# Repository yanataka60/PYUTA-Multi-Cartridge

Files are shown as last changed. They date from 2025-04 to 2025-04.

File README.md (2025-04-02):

# TOMY ぴゅう太用Multi Cartridge

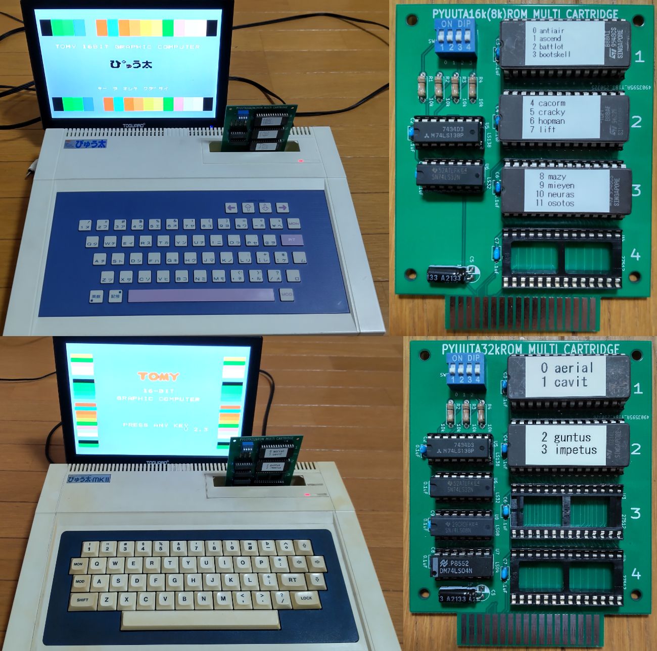
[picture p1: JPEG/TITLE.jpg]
Multi Cartridge


　いぬふとさんがたくさんのレトロPC用自作プログラムを公開してくださっており、ぴゅう太用としてはROMイメージでの公開となっています。

　そこで実機で気楽に遊べるようROMイメージをディップスイッチで切り替えられるカートリッジを作ってみました。

　公開されているROMイメージには(>8000～)、(>4000～)の二種類があり、それぞれ(>8000～)用の16K(8K)ROM Multi Cartridgeと(4000～)用の32KROM Multi Cartridgeを使用します。

#### 注)32KROM Multi Cartridgeを初代ぴゅう太で使用するにはゲームアダプター相当品が必要です。初代ぴゅう太のカートリッジスロットに32KROM Multi Cartridgeを挿入しても動作しません。

　16K(8K)ROM Multi Cartridgeはぴゅう太、ぴゅう太mk2で動作確認、32KROM Multi Cartridgeはぴゅう太+ゲームアダプター相当品、ぴゅう太mk2で動作確認を行いましたが、ぴゅう太Jr.も両方とも動作すると思います。

　なお、当然ですがROMへ書き込むための機器が別途必要となります。

## 16K(8K)ROM Multi Cartridge
### 回路図
　KiCadフォルダ内のPYUTA16k.pdfを参照してください。

[回路図](https://github.com/yanataka60/PYUTA-Multi-Cartridge/blob/main/Kicad/16K/PYUTA16k.pdf)

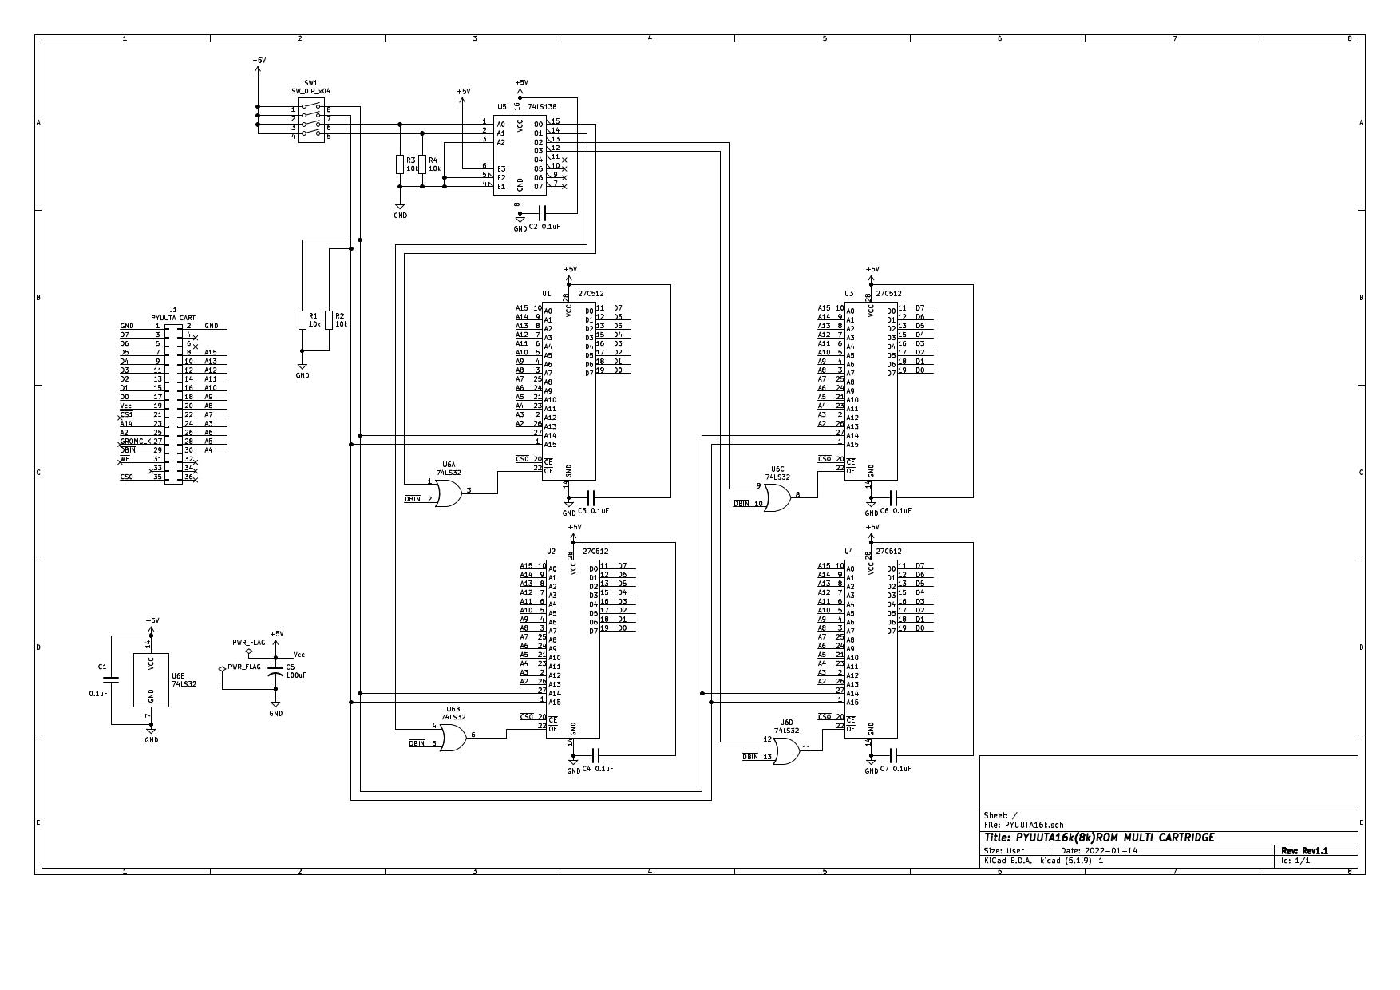
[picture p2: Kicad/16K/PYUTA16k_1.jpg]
16K


### 部品
|番号|品名|数量|備考|
| --- | --- | --- | --- |
|U1-U4|ROM 27512|1～4|最大4個|
|U5|74LS138|1||
|U6|74LS32|1||
|SW1|DIPスイッチ 4P|1|秋月電子通商 EDS104SZなど|
|R1-R4|カーボン抵抗 10KΩ|4||
|C1-C4、C6、C7|積層セラミックコンデンサ 0.1uF|6||
|C5|電解コンデンサ 16v100uF|1||
||28P ICソケット|4||
||16P ICソケット|1|使用は任意|
||14P ICソケット|1|使用は任意|

### ROMへの書込み
　ROMイメージを27512の0000h、4000h、8000h、C000hを先頭アドレスとして書き込みます。

### ROMイメージの切り替え
　DIPスイッチ1番、2番スイッチで0000h、4000h、8000h、C000hのイメージの切り替え、DIPスイッチ3番、4番スイッチでROMを選択できます。

　最大16種類のROMイメージを切り替え可能です。

## 32KROM Multi Cartridge
### 回路図
　KiCadフォルダ内のPYUTA32k.pdfを参照してください。

[回路図](https://github.com/yanataka60/PYUTA-Multi-Cartridge/blob/main/Kicad/32K/PYUTA32k.pdf)

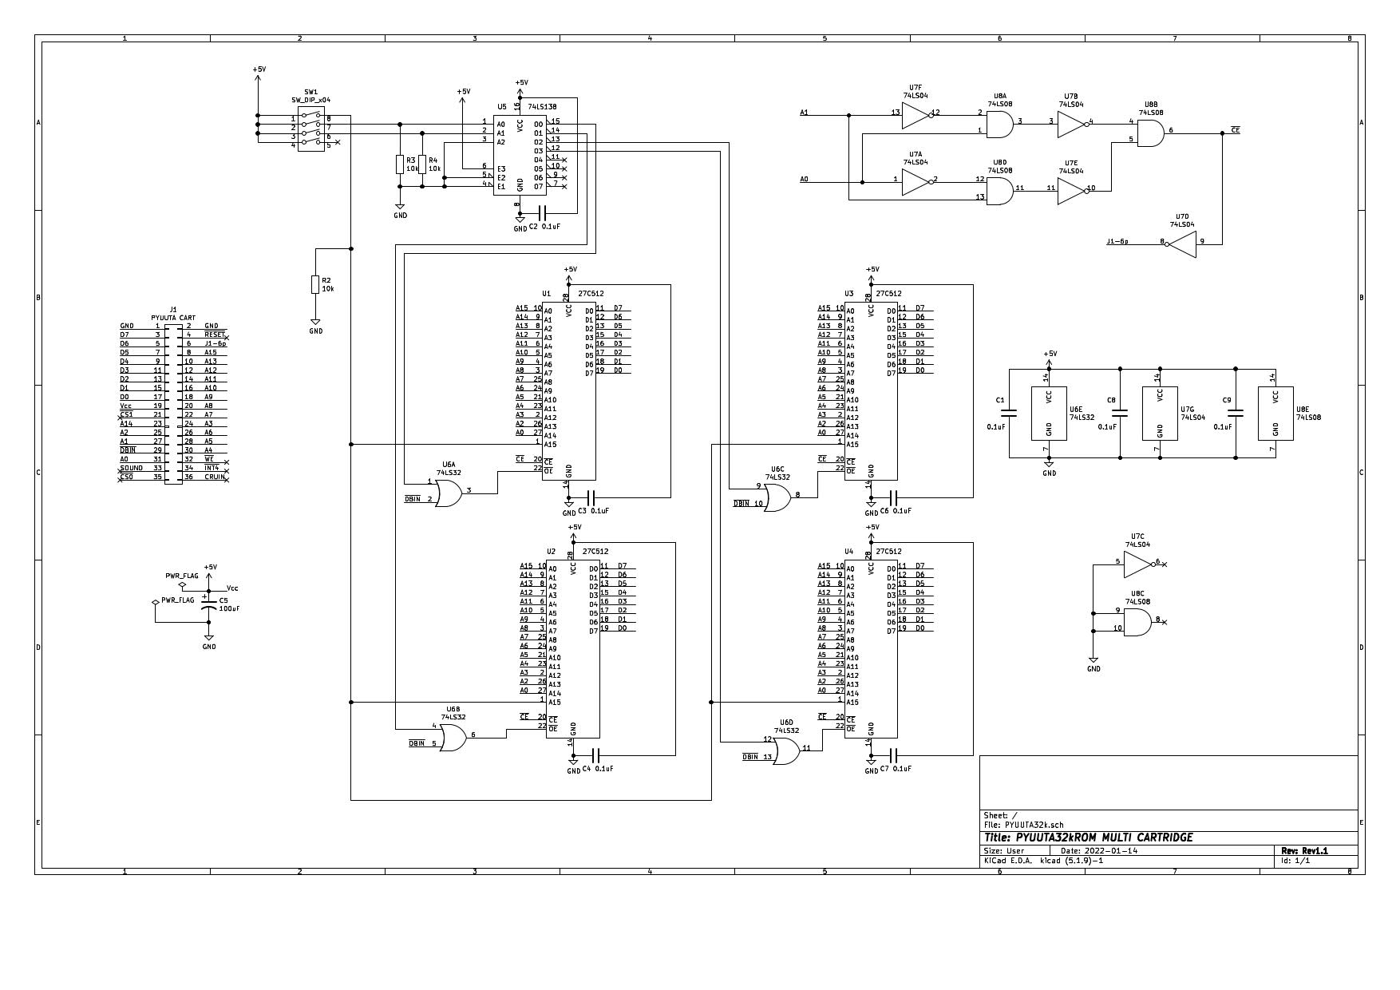
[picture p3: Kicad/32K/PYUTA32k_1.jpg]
32K


### 部品
|番号|品名|数量|備考|
| --- | --- | --- | --- |
|U1-U4|ROM 27512|1～4|最大4個|
|U5|74LS138|1||
|U6|74LS32|1||
|U7|74LS04|1||
|U8|74LS08|1||
|SW1|DIPスイッチ 4P|1|秋月電子通商 EDS104SZなど、3Pしか使っていないので3Pでも可|
|R2-R4|カーボン抵抗 10KΩ|3||
|C1-C4、C6-C9|積層セラミックコンデンサ 0.1uF|8||
|C5|電解コンデンサ 16v100uF|1||
||28P ICソケット|4||
||16P ICソケット|1|使用は任意|
||14P ICソケット|3|使用は任意|

### ROMへの書込み
　ROMイメージを27512の0000h、8000hを先頭アドレスとして書き込みます。

### ROMイメージの切り替え
　DIPスイッチ1番スイッチで0000h、8000hのイメージの切り替え、DIPスイッチ2番、3番スイッチでROMを選択できます。

　最大8種類のROMイメージを切り替え可能です。

## 謝辞
　たくさんのゲームを公開してくださっているいぬふと様、ありがとうございます。

　ぴゅう太の解析情報を公開してくださっているEnri様、ありがとうございます。

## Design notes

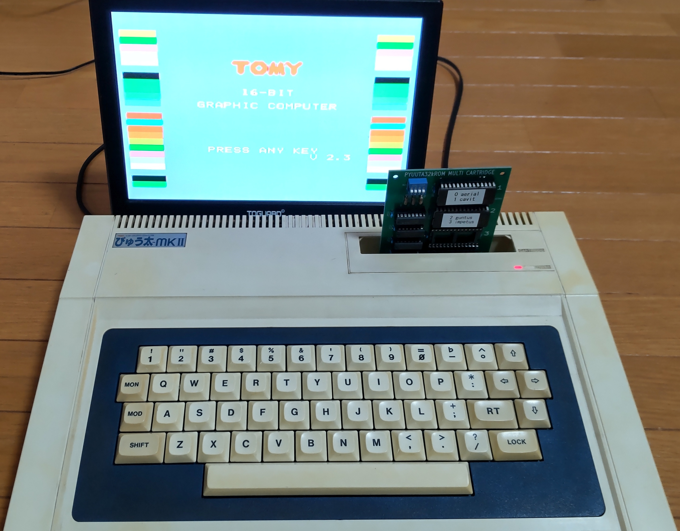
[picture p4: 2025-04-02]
JPEG/PYUTAmk2.jpg

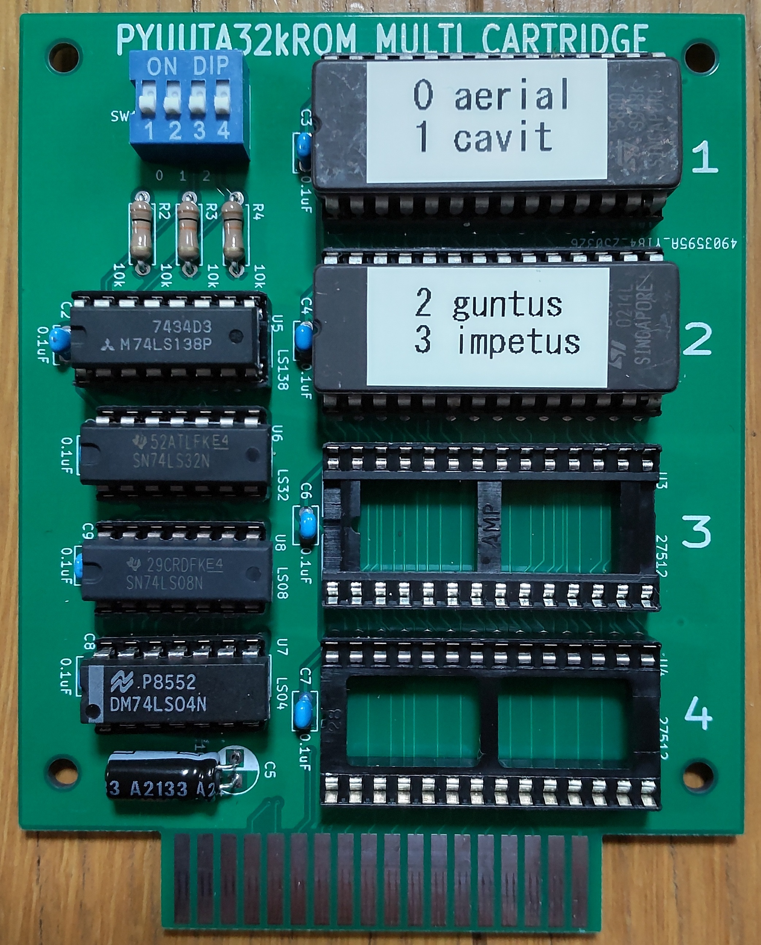
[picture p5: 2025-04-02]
JPEG/32kROM.jpg

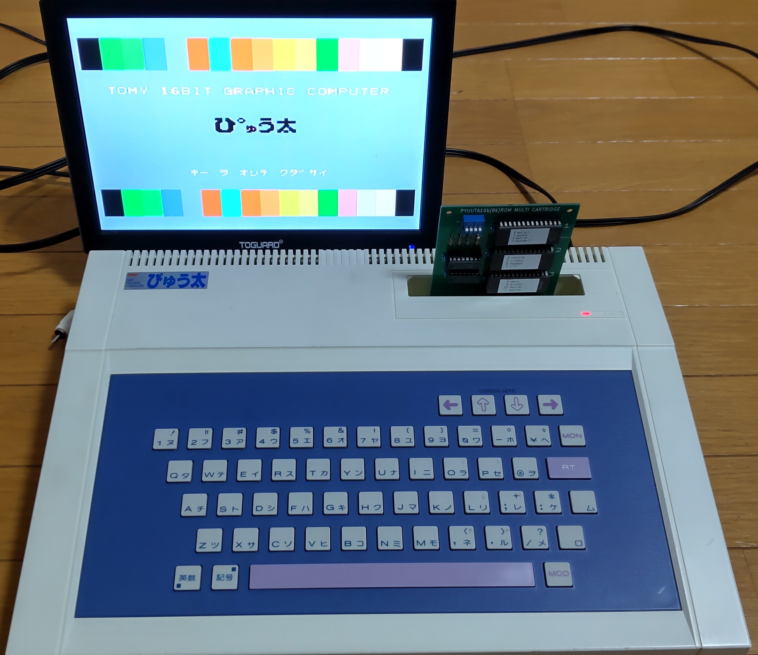
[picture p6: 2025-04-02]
JPEG/PYUTA.jpg

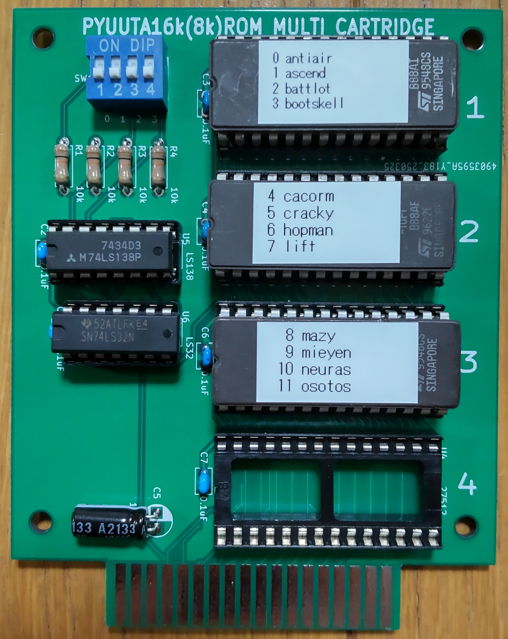
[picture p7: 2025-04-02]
JPEG/16kROM.jpg

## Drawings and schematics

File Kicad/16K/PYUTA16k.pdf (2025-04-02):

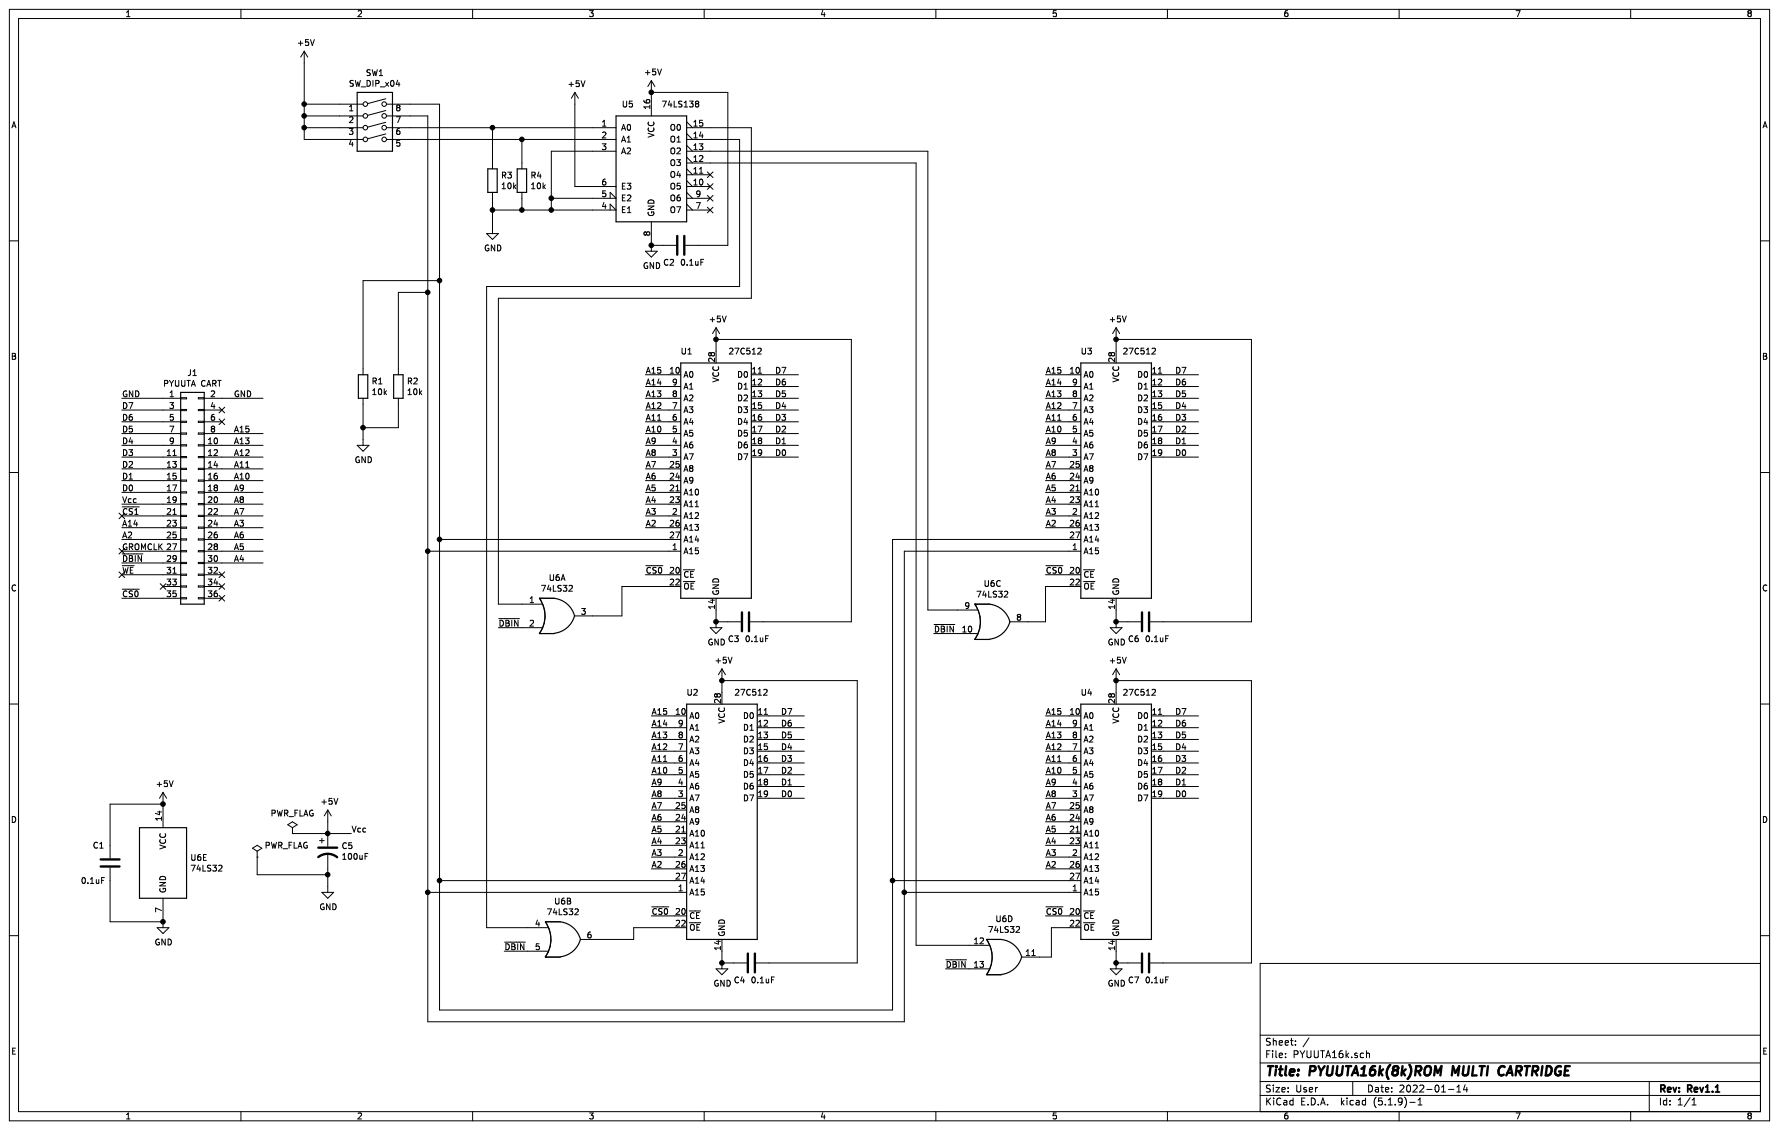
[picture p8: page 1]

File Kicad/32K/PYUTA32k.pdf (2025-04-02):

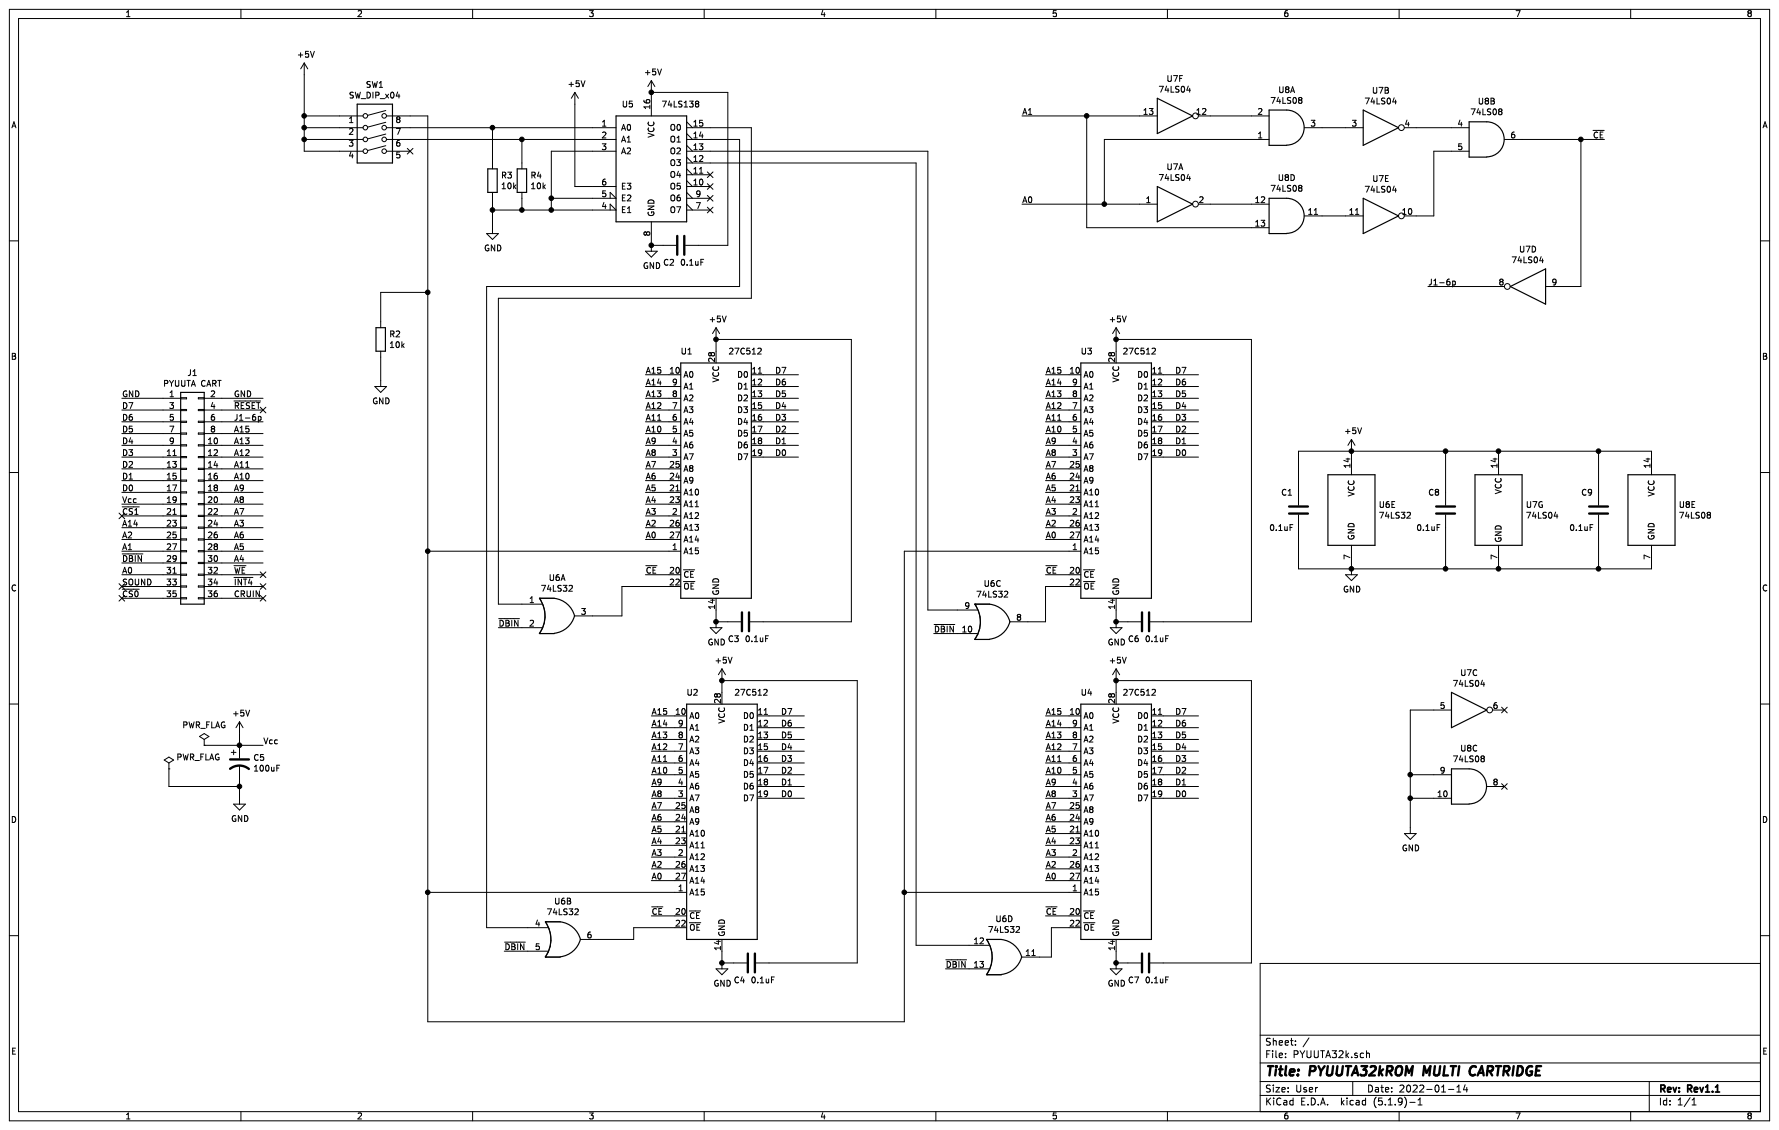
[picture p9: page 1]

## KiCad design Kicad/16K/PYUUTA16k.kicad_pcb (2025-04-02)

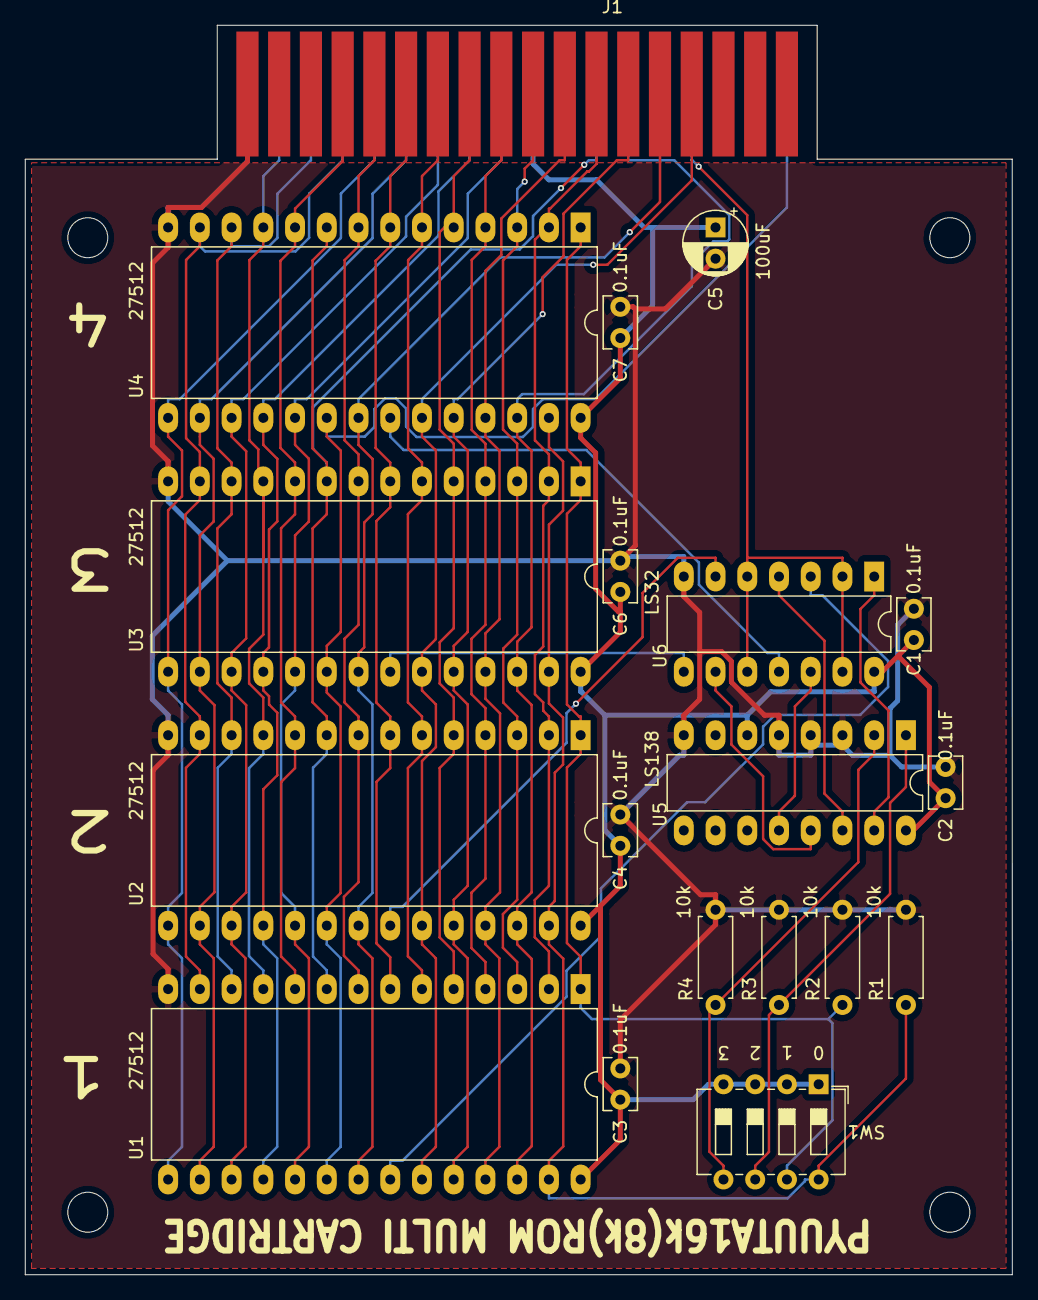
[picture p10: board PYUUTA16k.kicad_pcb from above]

Board: 2 copper layers, 79.0 x 100.0 mm, 23 parts (0 on the bottom side), 38 nets.

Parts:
C1, C2, C3, C4, C6, C7: 0.1uF; C_Rect_L4.0mm_W2.5mm_P2.50mm
C5: 100uF; CP_Radial_D5.0mm_P2.50mm
J1: PYUUTA CART; BUS_36Pin
MH1, MH2, MH3, MH4: MountingHole_3.2mm_M3
R1, R2, R3, R4: 10k; R_Axial_DIN0207_L6.3mm_D2.5mm_P7.62mm_Horizontal
SW1: SW_DIP_x04; SW_DIP_SPSTx04_Slide_6.7x11.72mm_W7.62mm_P2.54mm_LowProfile
U1, U2, U3, U4: 27C512; DIP-28_W15.24mm_LongPads
U5: 74LS138; DIP-16_W7.62mm_LongPads
U6: 74LS32; DIP-14_W7.62mm_LongPads

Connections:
+5V: C1.1, C2.2, C3.2, C4.2, C5.1, C6.2, C7.2, J1.19, SW1.1, SW1.2, SW1.3, SW1.4, U1.28, U2.28, U3.28, U4.28, U5.6, U5.16, U6.14
/A2: J1.25, U1.26, U2.26, U3.26, U4.26
/A3: J1.24, U1.2, U2.2, U3.2, U4.2
/A4: J1.30, U1.23, U2.23, U3.23, U4.23
/A5: J1.28, U1.21, U2.21, U3.21, U4.21
/A6: J1.26, U1.24, U2.24, U3.24, U4.24
/A7: J1.22, U1.25, U2.25, U3.25, U4.25
/A8: J1.20, U1.3, U2.3, U3.3, U4.3
/A9: J1.18, U1.4, U2.4, U3.4, U4.4
/A10: J1.16, U1.5, U2.5, U3.5, U4.5
/A11: J1.14, U1.6, U2.6, U3.6, U4.6
/A12: J1.12, U1.7, U2.7, U3.7, U4.7
/A13: J1.10, U1.8, U2.8, U3.8, U4.8
/A14: J1.23, U1.9, U2.9, U3.9, U4.9
/A15: J1.8, U1.10, U2.10, U3.10, U4.10
/D0: J1.17, U1.19, U2.19, U3.19, U4.19
/D1: J1.15, U1.18, U2.18, U3.18, U4.18
/D2: J1.13, U1.17, U2.17, U3.17, U4.17
/D3: J1.11, U1.16, U2.16, U3.16, U4.16
/D4: J1.9, U1.15, U2.15, U3.15, U4.15
/D5: J1.7, U1.13, U2.13, U3.13, U4.13
/D6: J1.5, U1.12, U2.12, U3.12, U4.12
/D7: J1.3, U1.11, U2.11, U3.11, U4.11
/~CS0: J1.35, U1.20, U2.20, U3.20, U4.20
/~DBIN: J1.29, U6.2, U6.5, U6.10, U6.13
GND: C1.2, C2.1, C3.1, C4.1, C5.2, C6.1, C7.1, J1.1, J1.2, R1.2, R2.2, R3.2, R4.2, U1.14, U2.14, U3.14, U4.14, U5.3, U5.4, U5.5, U5.8, U6.7
unnamed: R1.1, SW1.8, U1.27, U2.27, U3.27, U4.27
unnamed: R2.1, SW1.7, U1.1, U2.1, U3.1, U4.1
unnamed: R3.1, SW1.6, U5.1
unnamed: R4.1, SW1.5, U5.2
unnamed: U1.22, U6.3
unnamed: U2.22, U6.6
unnamed: U3.22, U6.8
unnamed: U4.22, U6.11
unnamed: U5.12, U6.12
unnamed: U5.13, U6.9
unnamed: U5.14, U6.4
unnamed: U5.15, U6.1
